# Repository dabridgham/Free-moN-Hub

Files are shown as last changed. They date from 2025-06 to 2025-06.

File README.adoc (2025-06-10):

= Free-monN Hub

This is a simple circuit board that acts as a wiring hub for a
Free-moN module or section.  It basically just replaces (some of) the
terminal strips that one might use on a simple module and adds a 12
VDC linear regulator, a reversing relay, and LEDs to indicate power on
the ACC and DCC busses.

See the https://github.com/dabridgham/Free-moN-Hub/wiki[wiki] for more
information.

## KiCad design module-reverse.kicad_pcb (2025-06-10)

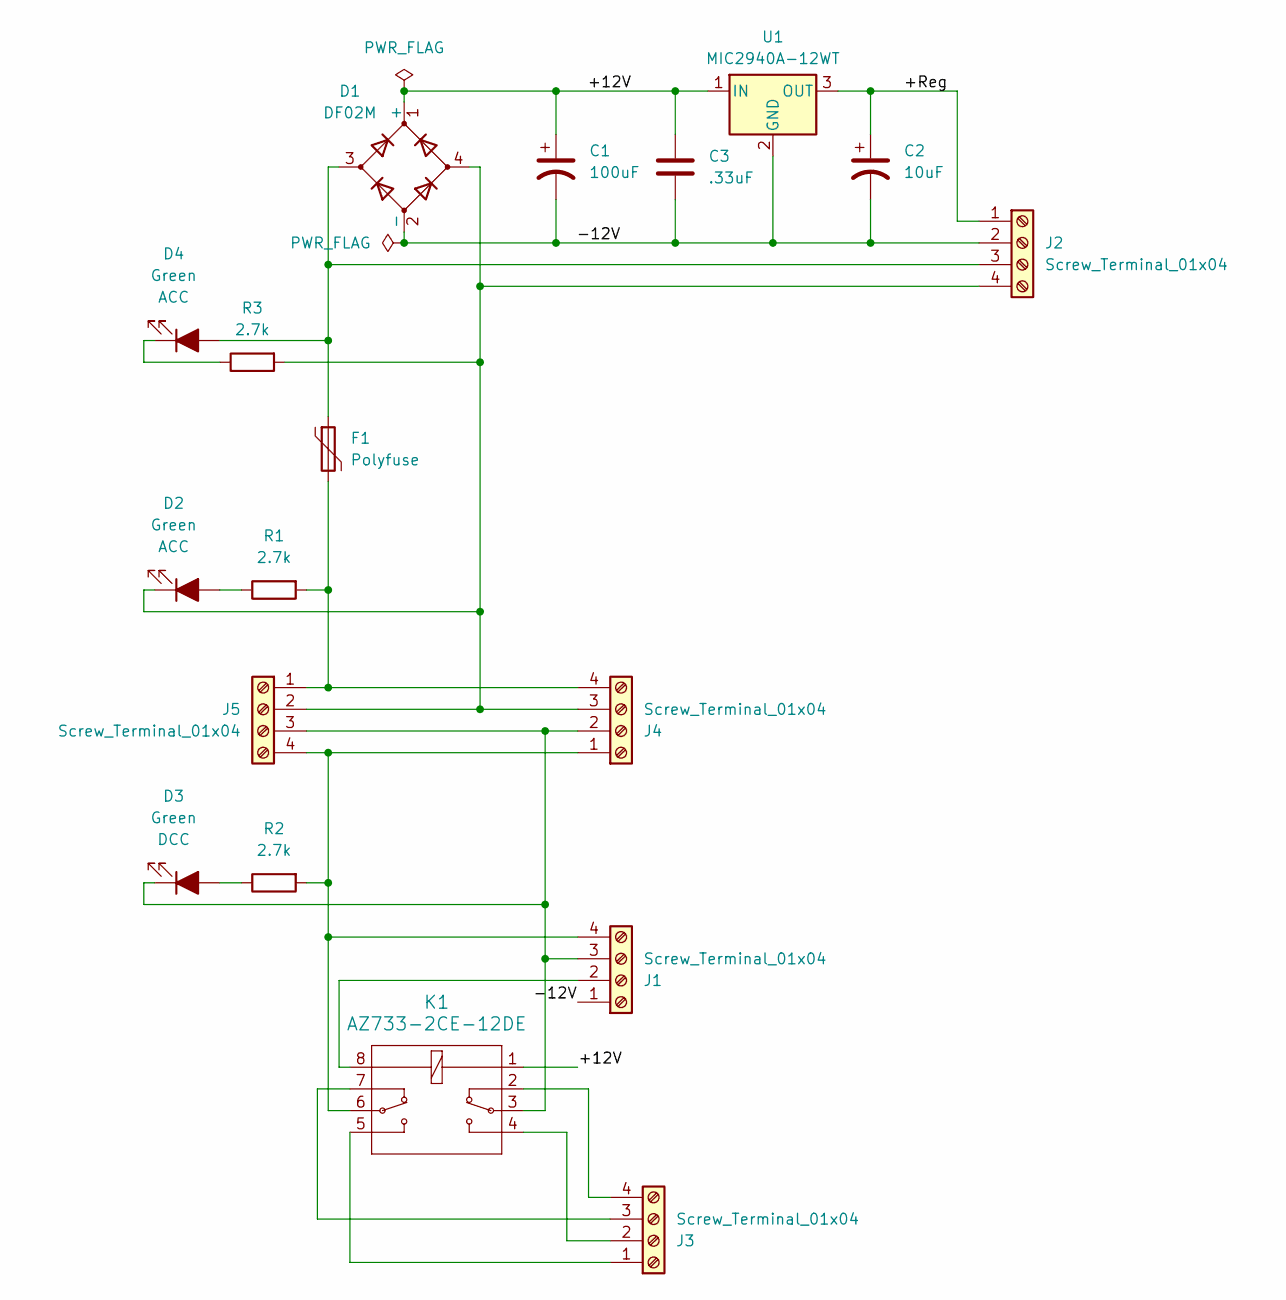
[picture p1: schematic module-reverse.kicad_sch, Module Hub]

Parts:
C1: 100uF; CP_Radial_D8.0mm_P3.50mm; MPN 50YXJ100MT78X11.5
C2: 10uF; CP_Radial_Tantal_D5.5mm_P5.00mm; MPN TAP106K025CRS
C3: .33uF; C_Disc_D5.0mm_W2.5mm_P5.00mm; MPN FA24X7R1H334KNU06
D1: DF02M; Diode_Bridge_DIP-4_W7.62mm_P5.08mm; MPN DF02M
D2, D3, D4: Green; LED_D3.0mm; MPN 151031VS06000
F1: Polyfuse; Fuse_Bourns_MF-RG300; MPN MF-R020
J1, J2, J3, J4, J5: Screw_Terminal_01x04; CUI_TB005-762-04BE; MPN TB005-762-04BE
K1: AZ733-2CE-12DE; AZ733-2C_AMZ; MPN AZ733-2CE-12DE
R1, R2, R3: 2.7k; R_Axial_DIN0207_L6.3mm_D2.5mm_P10.16mm_Horizontal; MPN CFR-25JB-52-2K7
U1: MIC2940A-12WT; TO-220-3_Vertical; MPN MIC2940A-12WT

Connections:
/+12V: C1.1, C3.1, D1.1 (+), K1.1, U1.1 (IN)
/+Reg: C2.1, J2.1, U1.3 (OUT)
/-12V: C1.2, C2.2, C3.2, D1.2 (-), J1.1, J2.2, U1.2 (GND)
unnamed: D2.2 (A), R1.1
unnamed: D1.4, D2.1 (K), J2.4, J4.3, J5.2, R3.2
unnamed: D3.2 (A), R2.1
unnamed: D3.1 (K), J1.3, J4.2, J5.3, K1.3
unnamed: D1.3, D4.2 (A), F1.1, J2.3
unnamed: D4.1 (K), R3.1
unnamed: J1.2, K1.8
unnamed: J1.4, J4.1, J5.4, K1.6, R2.2
unnamed: J3.1, K1.5
unnamed: J3.2, K1.4
unnamed: J3.3, K1.7
unnamed: J3.4, K1.2
unnamed: F1.2, J4.4, J5.1, R1.2

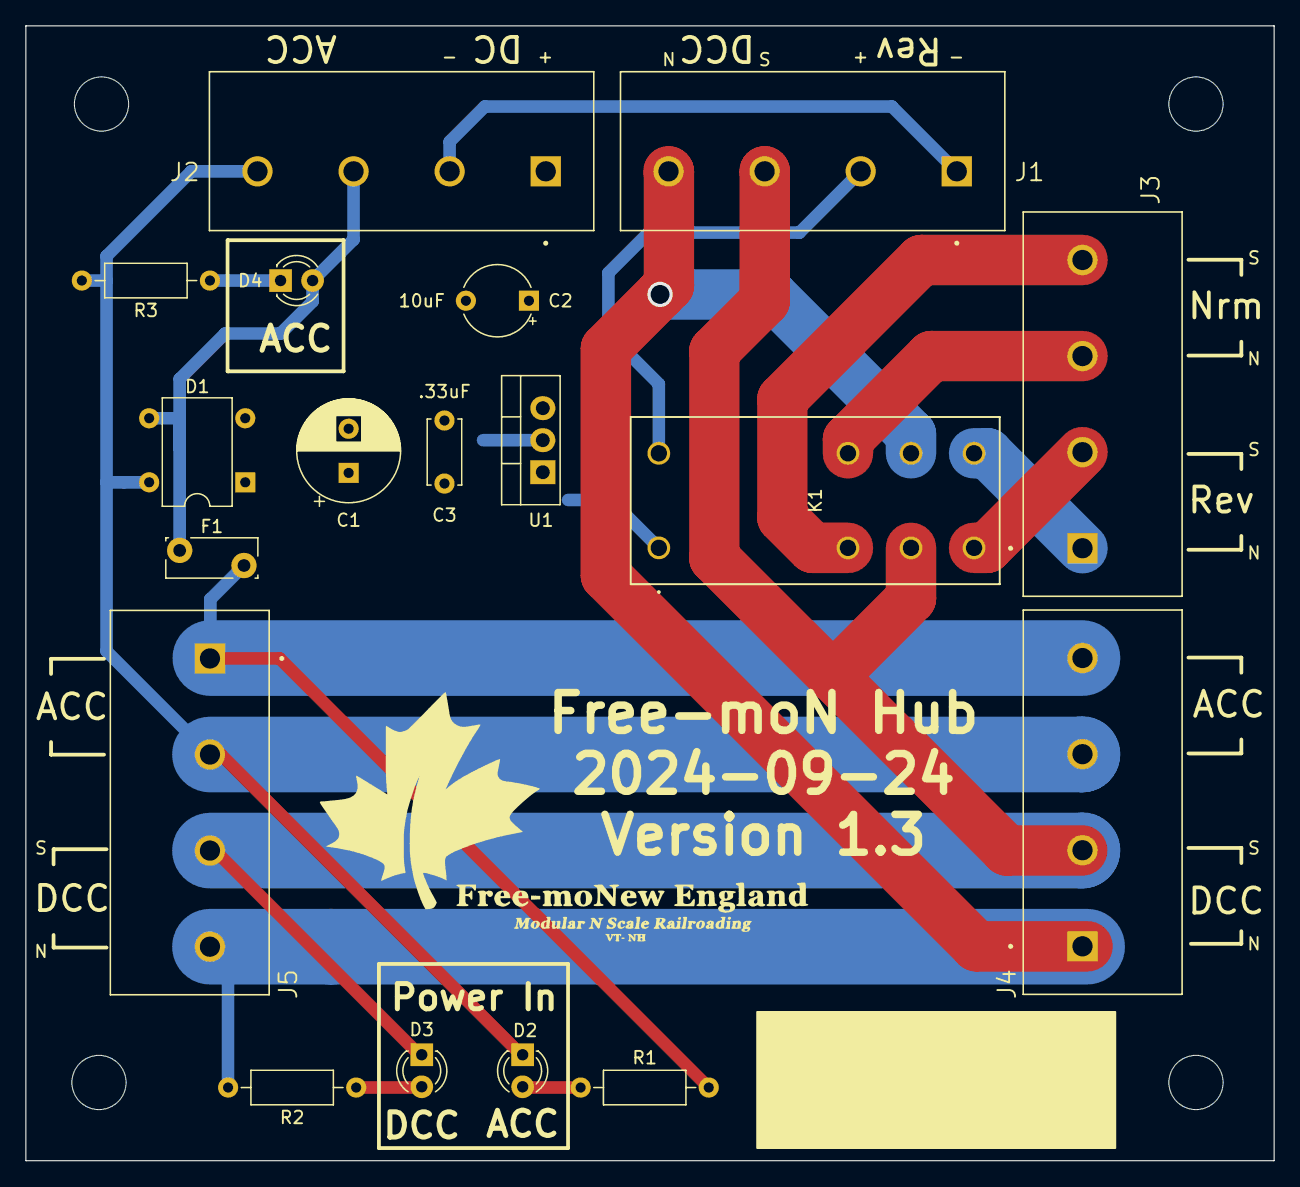
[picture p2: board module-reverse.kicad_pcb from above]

Board: 2 copper layers, 99.0 x 90.0 mm, 18 parts (0 on the bottom side), 16 nets.

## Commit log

2024-01-01 Initial version and first boards.
    [module.kicad_pcb, module.kicad_sch]
2024-01-01 Generated fabrication files for v1.0
    [module.kicad_pcb]
2024-01-01 Added the +/- and N/S indications to the silk layer
    [module.kicad_pcb]
2024-01-01 Corrected spelling of Free-moN
    [module.kicad_pcb]
2024-01-03 Added reversing relay and changed lower current screw terminals to a smaller style.
    [module.kicad_pcb, module.kicad_sch]
2024-01-03 Needed to actually add the files with their names changed.
    [module-reverse.kicad_pcb, module-reverse.kicad_sch]
2024-01-04 Changed the reversing output to have both Normal and Reverse outputs that go to the two branches instead of a single output that reverses.
    [module-reverse.kicad_pcb, module-reverse.kicad_sch]
2024-02-23 Added LEDs
    [module-reverse.kicad_pcb, module-reverse.kicad_sch]
2024-03-01 Updated reelase date and produced files for v1.1
    [module-reverse.kicad_pcb, module-reverse.kicad_sch]
2024-03-01 Forgot to save the file before committing in git. Now the date is updated
    [module-reverse.kicad_pcb]
2024-04-09 Moved power to relay to before the voltage regulator
    [module-reverse.kicad_pcb, module-reverse.kicad_sch]
2024-06-14 Updated to KiCad v8
    [module-reverse.kicad_pcb, module-reverse.kicad_sch]
2024-09-24 Added a PTC fuse to the ACC power and an additional LED to show its status
    [module-reverse.kicad_pcb, module-reverse.kicad_sch]
2025-02-09 Updated LEDs
    [module-reverse.kicad_pcb, module-reverse.kicad_sch]
2025-06-10 Updated to KiCad 9.0
    [module-reverse.kicad_pcb, module-reverse.kicad_sch]
